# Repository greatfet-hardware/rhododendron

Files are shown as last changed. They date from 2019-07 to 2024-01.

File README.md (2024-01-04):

# GreatFET Rhododendron

This is very early progress of a High-Speed USB analysis neighbor for GreatFET. More details to come.

## PCB

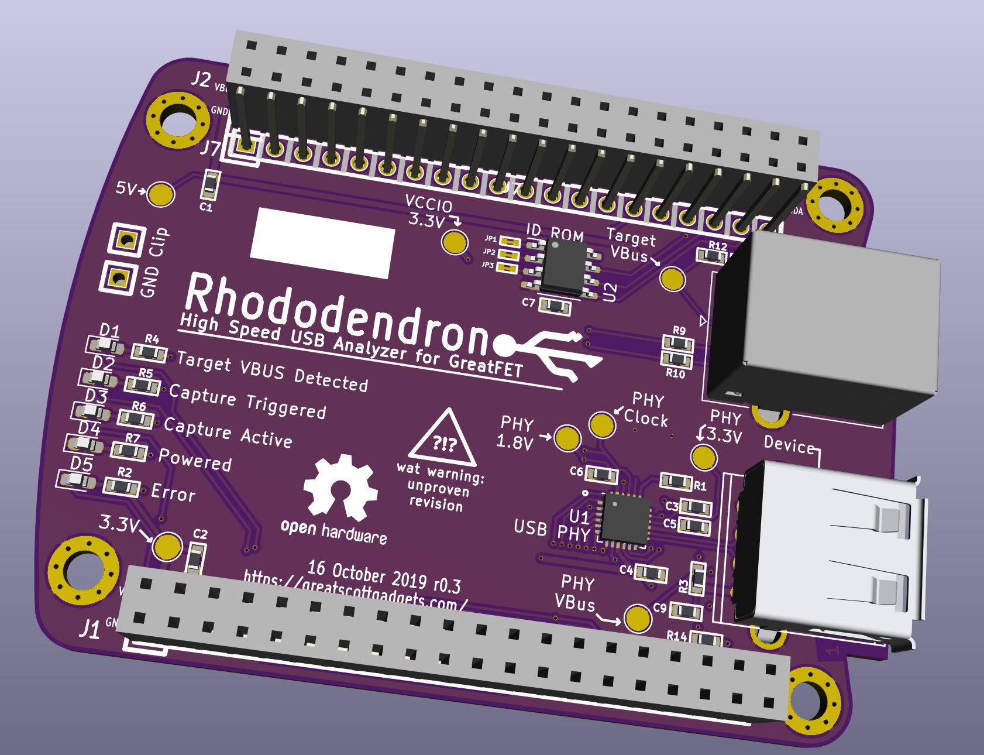
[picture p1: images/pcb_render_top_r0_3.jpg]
PCB r0.3 (top view)


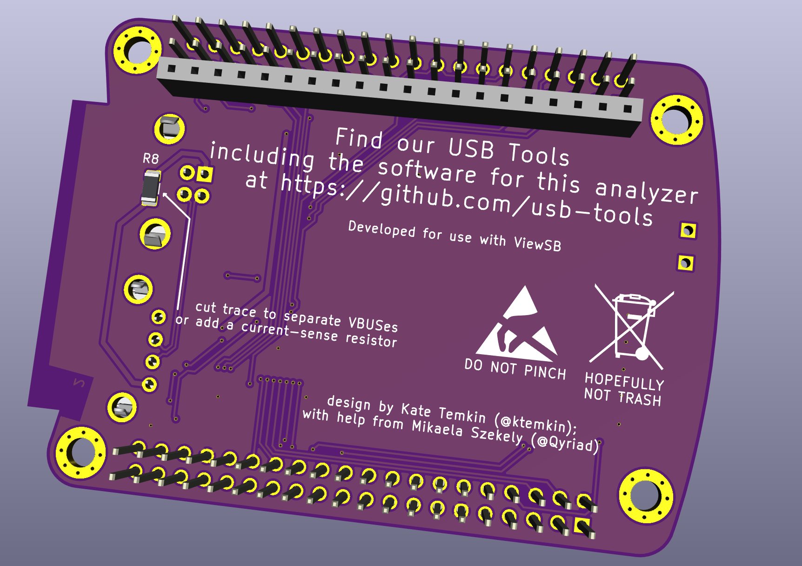
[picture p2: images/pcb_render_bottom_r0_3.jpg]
PCB r0.3 (bottom view)


Pictures by [Kate Temkin](https://twitter.com/ktemkin/status/1184521332832161792)

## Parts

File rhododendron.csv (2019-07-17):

Reference | Quantity | Value | Footprint | Datasheet | Note | Manufacturer | Part Number | Manuf P/N | Description
C3 C4 | 2 | 0.1uF | gsg-modules:0603 | ~
C5 C6 C1 C2 | 4 | 1uF | gsg-modules:0603 | ~
C8 C7 | 2 | 8.2pF | gsg-modules:0603 | ~
C9-DNP1 | 1 | 2.2uF | gsg-modules:0603 | ~
D1 D2 D3 D4 | 4 | LED | LED_SMD:LED_0603_1608Metric_Pad1.05x0.95mm_HandSolder | ~
J1 J2 | 2 | Conn_02x20_Odd_Even | gsg-modules:HEADER-2x20 | ~
J3 | 1 | Conn_02x08_Counter_Clockwise | gsg-modules:HEADER-2x8 | ~
J4 | 1 | USB-A-SHIELDED | rhododendron:CONN-Amphenol-UE27AC54100 |  |  |  |  | 87583-2010BLF
J5 | 1 | USB-B-SHIELDED | rhododendron:USB_B_OST_USB-B1HSxx_Horizontal
J7 | 1 | BONUS_ROW | gsg-modules:HEADER-1x20 |  | DNP | Samtec | SSQ-120-23-G-S |  | CONN RCPT .100 20POS SINGLE-ROW STACKING GOLD"
JP1 JP2 | 2 | Jumper_NC_Small | gsg-modules:0402-SHORT-10MIL | ~
MH3 MH4 MH1 MH2 | 4 | MOUNTING_HOLE | gsg-modules:HOLE126MIL-COPPER |  | DNP
R1 | 1 | 8.06k+1% | gsg-modules:0603 | ~
R2 | 1 | 1M | gsg-modules:0603 | ~
R3 | 1 | 20k+5% | gsg-modules:0603 | ~
R4 R5 R6 R7 | 4 | 330 | gsg-modules:0603 | ~
R8 | 1 | DNP | Resistor_SMD:R_1206_3216Metric | ~
TP1 TP5 TP4 TP8 TP6 TP2 TP3 | 7 | TestPoint | TestPoint:TestPoint_Pad_D2.0mm | ~
TP10 TP9 | 2 | TestPoint | gsg-modules:HEADER-1x1 | ~
U1 | 1 | USB3343 | Package_DFN_QFN:VQFN-24-1EP_4x4mm_P0.5mm_EP2.45x2.45mm
Y1 | 1 | 26MHz | gsg-modules:XTAL3.2x2.5mm | https://support.epson.biz/td/api/doc_check.php?dl=brief_TSX-3225&lang=en |  | Epson | TSX-3225 26.0000MF09Z-AC0

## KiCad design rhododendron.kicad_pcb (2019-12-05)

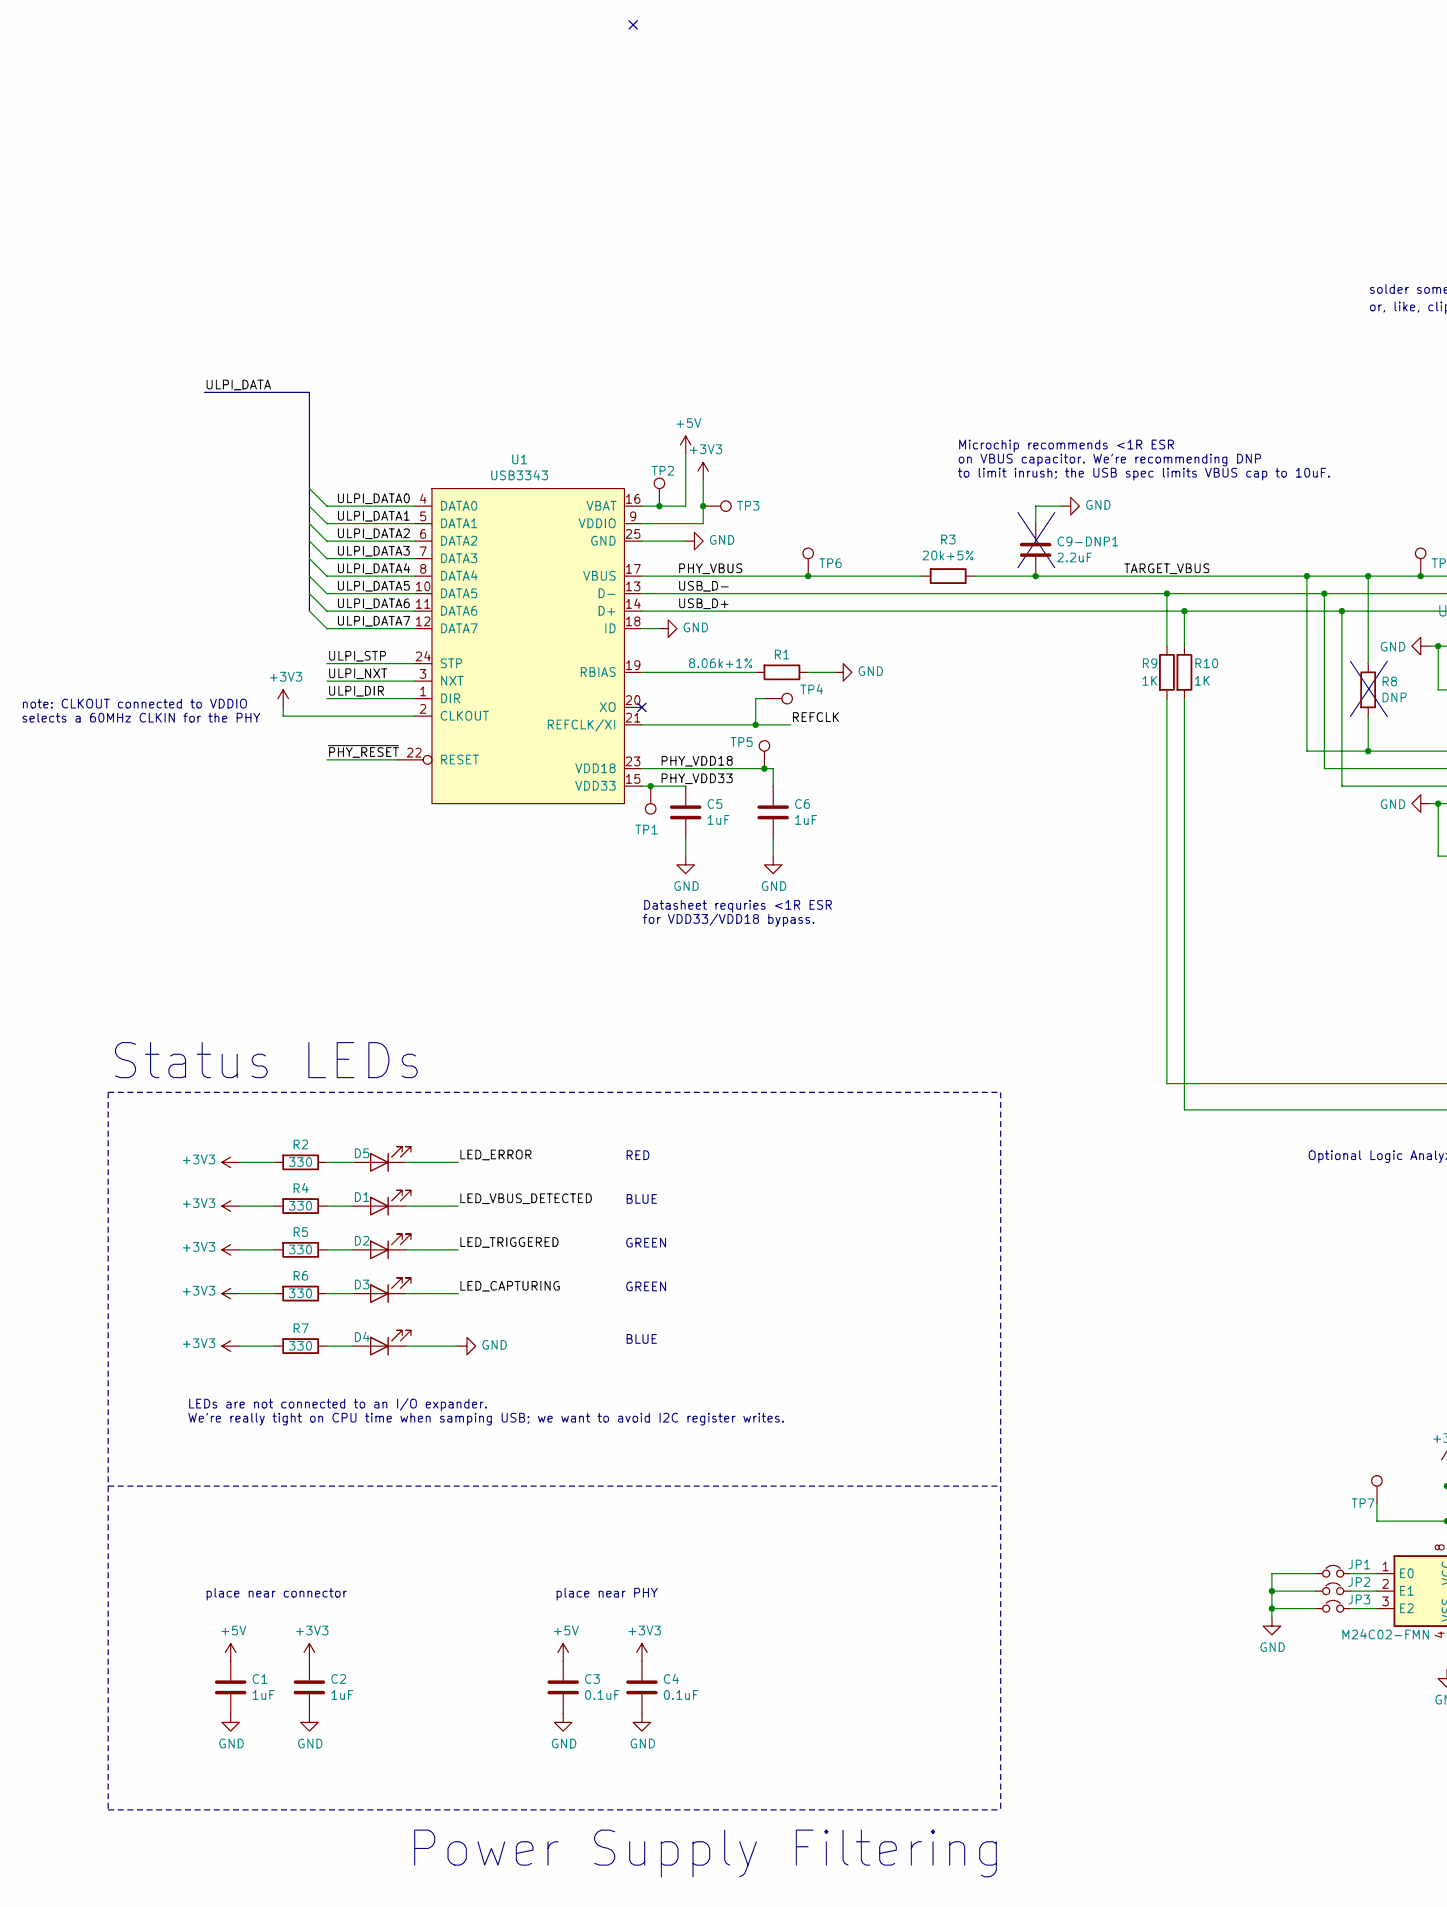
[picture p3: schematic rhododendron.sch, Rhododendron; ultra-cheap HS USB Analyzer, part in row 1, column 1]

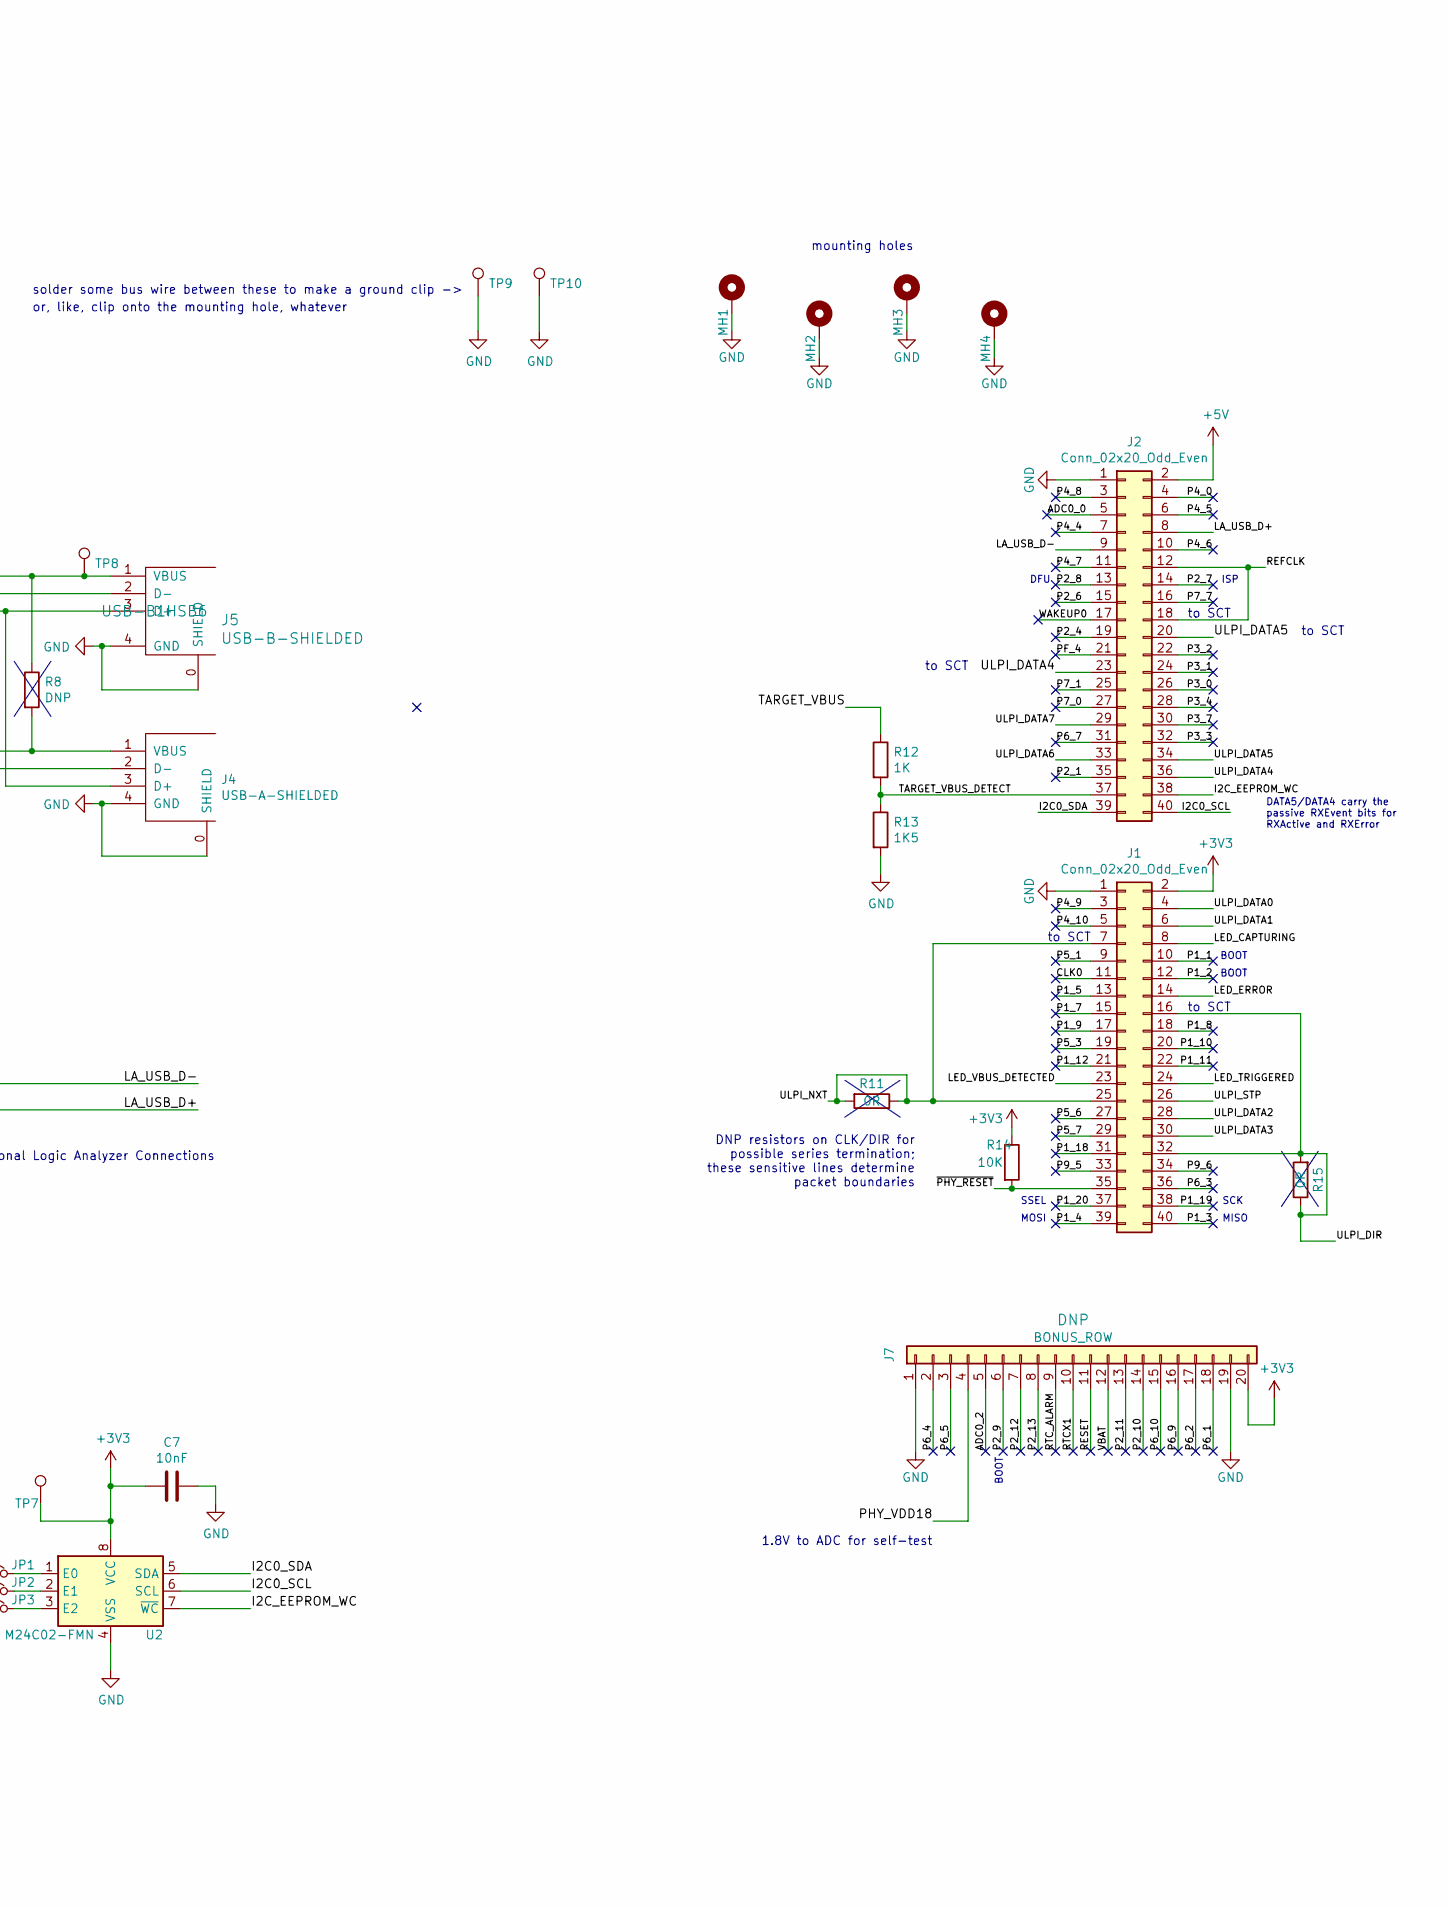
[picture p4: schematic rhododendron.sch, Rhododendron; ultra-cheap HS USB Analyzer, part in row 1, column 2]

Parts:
C1, C2, C5, C6: 1uF; 0603
C3, C4: 0.1uF; 0603
C7: 10nF; 0603
C9-DNP1: 2.2uF; 0603
D1, D2, D3, D4, D5: LED; LED_0603_1608Metric_Pad1.05x0.95mm_HandSolder
J1, J2: Conn_02x20_Odd_Even; HEADER-2x20
J4: USB-A-SHIELDED; CONN-Amphenol-UE27AC54100; Manuf P/N UE27AC54100
J5: USB-B-SHIELDED; USB_B_OST_USB-_Horizontal
J7: BONUS_ROW; HEADER-1x20; Part Number SSQ-120-23-G-S
JP1, JP2, JP3: Jumper_NC_Small; 0402-SHORT-10MIL
MH1, MH2, MH3, MH4: MOUNTING_HOLE; HOLE126MIL-COPPER
R1: 8.06k+1%; 0603
R2, R4, R5, R6, R7: 330; 0603
R3: 20k+5%; 0603
R8: DNP; R_1206_3216Metric
R9, R10, R12: 1K; 0603
R11, R15: 0R; 0603
R13: 1K5; 0603
R14: 10K; 0603
TP1, TP2, TP3, TP4, TP5, TP6, TP7, TP8: TestPoint; TestPoint_Pad_D2.0mm
TP9, TP10: TestPoint; HEADER-1x1
U1: USB3343; VQFN-24-1EP_4x4mm_P0.5mm_EP2.45x2.45mm
U2: M24C02-FMN; SOIC-8_3.9x4.9mm_P1.27mm

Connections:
+3V3: C2.1, C4.1, C7.2, J1.2, J7.20, R2.2, R4.2, R5.2, R6.2, R7.2, R14.1, TP3.1, TP7.1, U1.2 (CLKOUT), U1.9 (VDDIO), U2.8 (VCC)
+5V: C1.1, C3.1, J2.2, TP2.1, U1.16 (VBAT)
/ADC0_0: J2.5
/ADC0_2: J7.5
/CLK0: J1.11
/I2C0_SCL: J2.40, U2.6 (SCL)
/I2C0_SDA: J2.39, U2.5 (SDA)
/I2C_EEPROM_WC: J2.38, U2.7 (~WC)
/LA_USB_D+: J2.8, R10.2
/LA_USB_D-: J2.9, R9.2
/LED_CAPTURING: D3.1 (K), J1.8
/LED_ERROR: D5.1 (K), J1.14
/LED_TRIGGERED: D2.1 (K), J1.24
/LED_VBUS_DETECTED: D1.1 (K), J1.23
/P1_1: J1.10
/P1_2: J1.12
/P1_3: J1.40
/P1_4: J1.39
/P1_5: J1.13
/P1_7: J1.15
/P1_8: J1.18
/P1_9: J1.17
/P1_10: J1.20
/P1_11: J1.22
/P1_12: J1.21
/P1_18: J1.31
/P1_19: J1.38
/P1_20: J1.37
/P2_1: J2.35
/P2_4: J2.19
/P2_6: J2.15
/P2_7: J2.14
/P2_8: J2.13
/P2_9: J7.6
/P2_10: J7.14
/P2_11: J7.13
/P2_12: J7.7
/P2_13: J7.8
/P3_0: J2.26
/P3_1: J2.24
/P3_2: J2.22
/P3_3: J2.32
/P3_4: J2.28
/P3_7: J2.30
/P4_0: J2.4
/P4_4: J2.7
/P4_5: J2.6
/P4_6: J2.10
/P4_7: J2.11
/P4_8: J2.3
/P4_9: J1.3
/P4_10: J1.5
/P5_1: J1.9
/P5_3: J1.19
/P5_6: J1.27
/P5_7: J1.29
/P6_1: J7.18
/P6_2: J7.17
/P6_3: J1.36
/P6_4: J7.2
/P6_5: J7.3
/P6_7: J2.31
/P6_9: J7.16
/P6_10: J7.15
/P7_0: J2.27
/P7_1: J2.25
/P7_7: J2.16
/P9_5: J1.33
/P9_6: J1.34
/PF_4: J2.21
/PHY_VBUS: R3.2, TP6.1, U1.17 (VBUS)
/PHY_VDD18: C6.1, J7.4, TP5.1, U1.23 (VDD18)
/PHY_VDD33: C5.2, TP1.1, U1.15 (VDD33)
/REFCLK: J2.12, J2.18, TP4.1, U1.21 (REFCLK/XI)
/RESET: J7.11
/RTCX1: J7.10
/RTC_ALARM: J7.9
/TARGET_VBUS: C9-DNP1.2, J4.1 (VBUS), J5.1 (VBUS), R3.1, R8.1, R8.2, R12.1, TP8.1
/TARGET_VBUS_DETECT: J2.37, R12.2, R13.1
/ULPI_DATA0: J1.4, U1.4 (DATA0)
/ULPI_DATA1: J1.6, U1.5 (DATA1)
/ULPI_DATA2: J1.28, U1.6 (DATA2)
/ULPI_DATA3: J1.30, U1.7 (DATA3)
/ULPI_DATA4: J2.23, J2.36, U1.8 (DATA4)
/ULPI_DATA5: J2.20, J2.34, U1.10 (DATA5)
/ULPI_DATA6: J2.33, U1.11 (DATA6)
/ULPI_DATA7: J2.29, U1.12 (DATA7)
/ULPI_DIR: J1.16, J1.32, R15.1, R15.2, U1.1 (DIR)
/ULPI_NXT: J1.7, J1.25, R11.1, R11.2, U1.3 (NXT)
/ULPI_STP: J1.26, U1.24 (STP)
/USB_D+: J4.3 (D+), J5.3 (D+), R10.1, U1.14 (D+)
/USB_D-: J4.2 (D-), J5.2 (D-), R9.1, U1.13 (D-)
/VBAT: J7.12
/WAKEUP0: J2.17
/~PHY_RESET: J1.35, R14.2, U1.22 (RESET)
GND: C1.2, C2.2, C3.2, C4.2, C5.1, C6.2, C7.1, C9-DNP1.1, D4.1 (K), J1.1, J2.1, J4.0 (SHIELD), J4.4 (GND), J5.0 (SHIELD), J5.4 (GND), J7.1, J7.19, JP1.1, JP2.1, JP3.1, MH1.1, MH2.1, MH3.1, MH4.1, R1.1, R13.2, TP9.1, TP10.1, U1.18 (ID), U1.25 (GND), U2.4 (VSS)
unnamed: D1.2 (A), R4.1
unnamed: D2.2 (A), R5.1
unnamed: D3.2 (A), R6.1
unnamed: D4.2 (A), R7.1
unnamed: D5.2 (A), R2.1
unnamed: JP1.2, U2.1 (E0)
unnamed: JP2.2, U2.2 (E1)
unnamed: JP3.2, U2.3 (E2)
unnamed: R1.2, U1.19 (RBIAS)

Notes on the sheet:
BOOT
Datasheet requries <1R ESR for VDD33/VDD18 bypass.
Microchip recommends <1R ESR on VBUS capacitor. We're recommending DNP to limit inrush; the USB spec limits VBUS cap to 10uF.
LEDs are not connected to an I/O expander. We're really tight on CPU time when samping USB; we want to avoid I2C register writes.
Optional Logic Analyzer Connections
DFU
SSEL
SCK
MOSI
MISO
Status LEDs
Power Supply Filtering
place near connector
place near PHY
solder some bus wire between these to make a ground clip ->
or, like, clip onto the mounting hole, whatever
mounting holes
note: CLKOUT connected to VDDIO selects a 60MHz CLKIN for the PHY
ISP
1.8V to ADC for self-test
RED
BLUE
GREEN
DATA5/DATA4 carry the passive RXEvent bits for RXActive and RXError
to SCT
DNP resistors on CLK/DIR for possible series termination; these sensitive lines determine packet boundaries

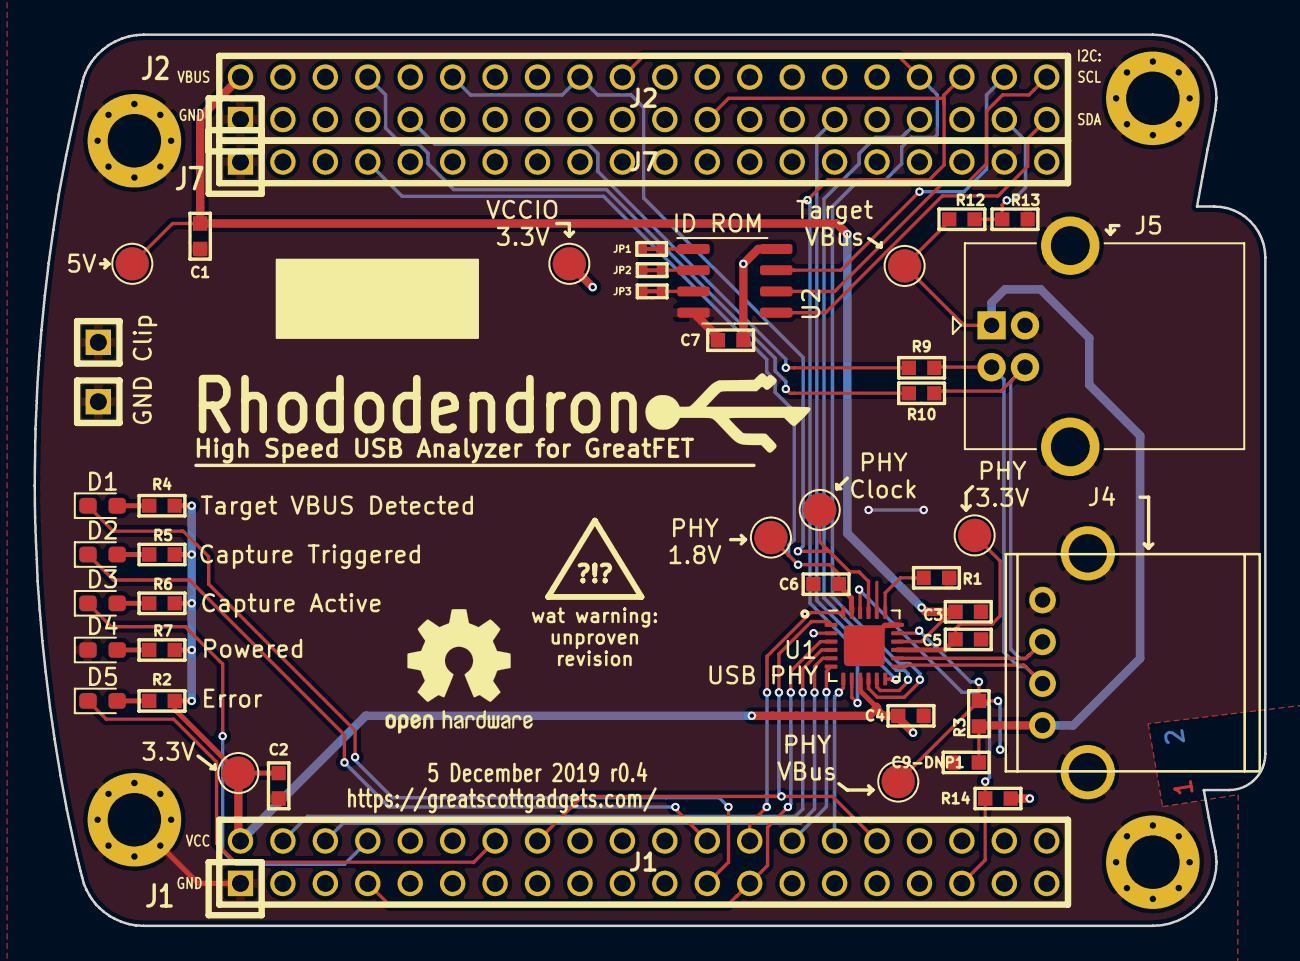
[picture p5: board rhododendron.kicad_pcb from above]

Board: 2 copper layers, 73.7 x 53.3 mm, 50 parts (1 on the bottom side), 41 nets.

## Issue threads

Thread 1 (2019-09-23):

J7_P10 incorrectly grounded

mossmann, 2019-09-23:
It used to be grounded on Azalea but was changed to RTCX1.

falcnix, 2023-03-10:
is the bug resolved? and If I have to order one in India, how do I go about doing it?

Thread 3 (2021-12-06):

Add license file

straithe, 2021-12-06:

falcnix, 2023-03-20:
where and how can I order this?

straithe, 2023-03-21:
This is not currently for sale. You can use the information in this repository to make one yourself. Next time, please open your question in a new issue.

falcnix, 2023-03-21:
>

Hey I am sorry, I was so eager that didn't quite notice I was in another issue. But yeah, Thanks!

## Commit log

2019-05-02 initial commit of r0 Rhodadendon schematic
    [rhodadendron.kicad_pcb, rhodadendron.sch]
2019-05-08 fix my inability to spell rhododendron :)
    [rhododendron.kicad_pcb, rhododendron.sch]
2019-07-17 r0.2: finalize for ordering; improve silkscreen; minor tweaks
    [rhododendron.csv, rhododendron.kicad_pcb, rhododendron.sch]
2019-10-16 r0.3: capture schematic with all changes
    [rhododendron.sch]
2019-10-16 r0.3: route the changes made in the r0.3 schematic
    [rhododendron.kicad_pcb, rhododendron.sch]
2019-10-16 r0.3: add 3d models and prepare for plotting
    [rhododendron.kicad_pcb, rhododendron.sch]
2019-10-16 r0.3: round the corners on the support ledge
    [rhododendron.kicad_pcb]
2019-12-05 r0.4: correct two "wasted" header pins (incorrectly connected to 3V3)
    [rhododendron.kicad_pcb]
2020-07-03 adopt OSHWA convention for SPI signal names https://www.oshwa.org/a-resolution-to-redefine-spi-signal-names
    [rhododendron.sch]
2022-03-04 Add pcb images from @ktemkin

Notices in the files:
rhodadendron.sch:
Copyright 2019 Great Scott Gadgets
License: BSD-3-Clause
